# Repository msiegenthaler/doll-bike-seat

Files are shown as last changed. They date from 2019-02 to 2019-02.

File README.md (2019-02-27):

# Doll Bike Seat

OpenSCAD model for a bike seat for dolls for 3D printing.

The seat fits a Kokua Like-to-Bike children bike.

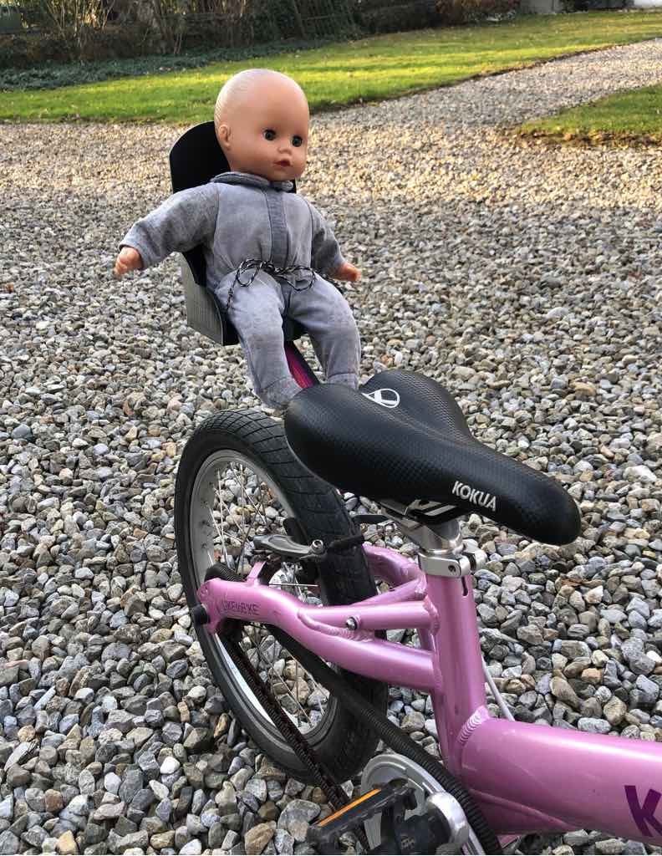
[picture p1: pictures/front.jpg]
Front

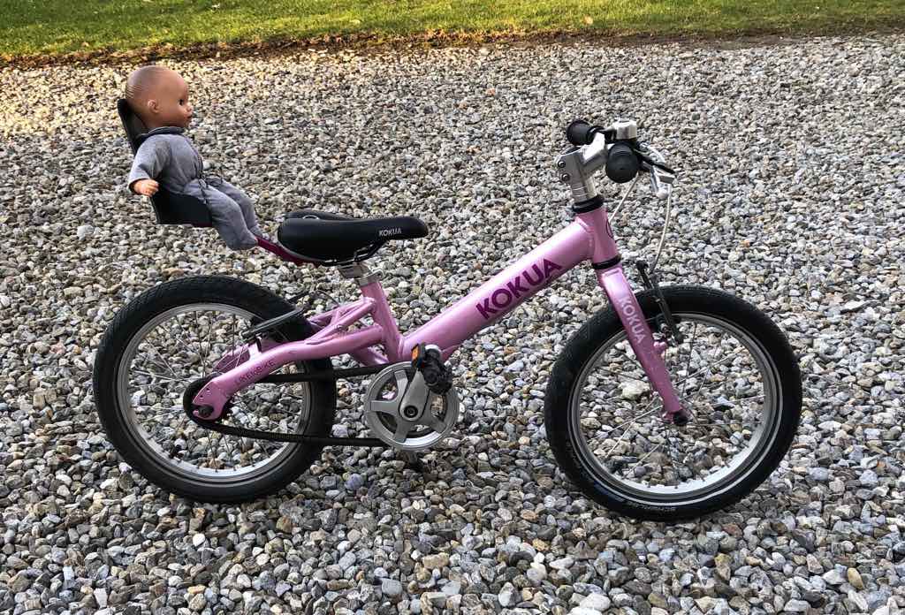
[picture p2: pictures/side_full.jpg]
Full

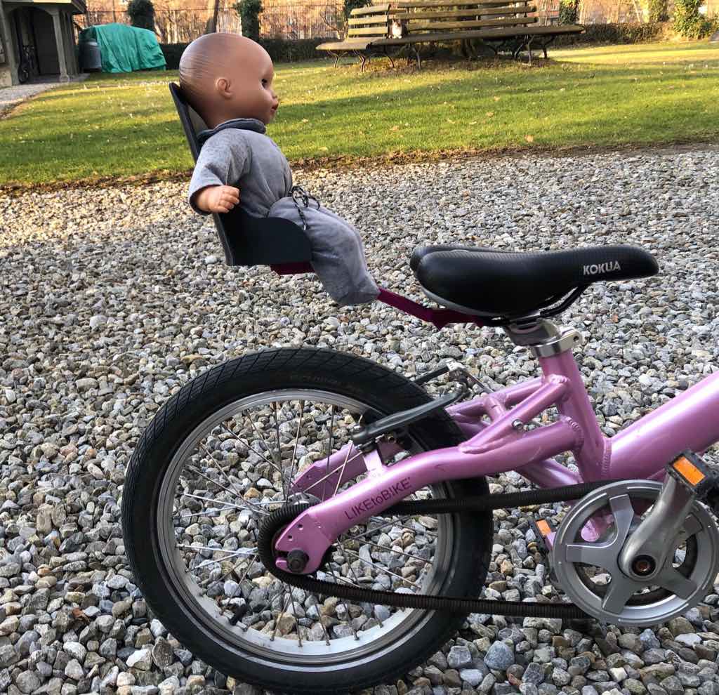
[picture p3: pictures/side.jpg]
Side

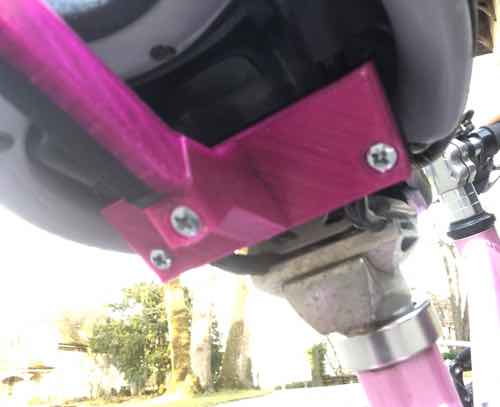
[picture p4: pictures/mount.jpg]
Holder


## Printing

All parts were printed using PET. PLA/ABS are not strong enough.

Here's the recommended settings per part:

- seat: 20% infill, no support
- seat holder: 50% infill, no support
- case top: 50% infill, no support
- case bottom: 50% infill, no support
- rod: 60% infill, support on build plate

## Assembling

You need 6 flat-heat M4 screws and 6 M4 nuts to assemble the parts.

The screws should have the following lengths:

- 3x 10mm M4 (for the seat)
- 2x 15mm M4 (for the case left/right)
- 1x 50mm M4 (for the case middle)

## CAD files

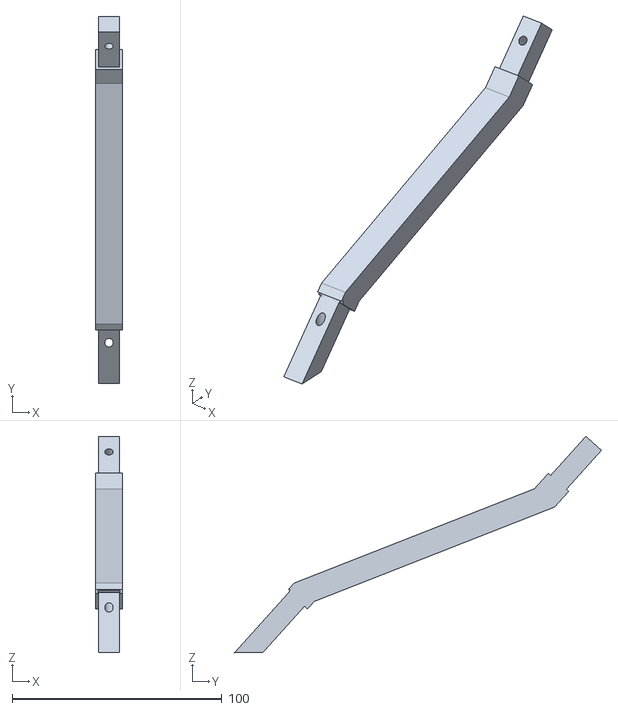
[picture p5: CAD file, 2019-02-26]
models/rod_v9.stl
13.0 x 174.8 x 103.1

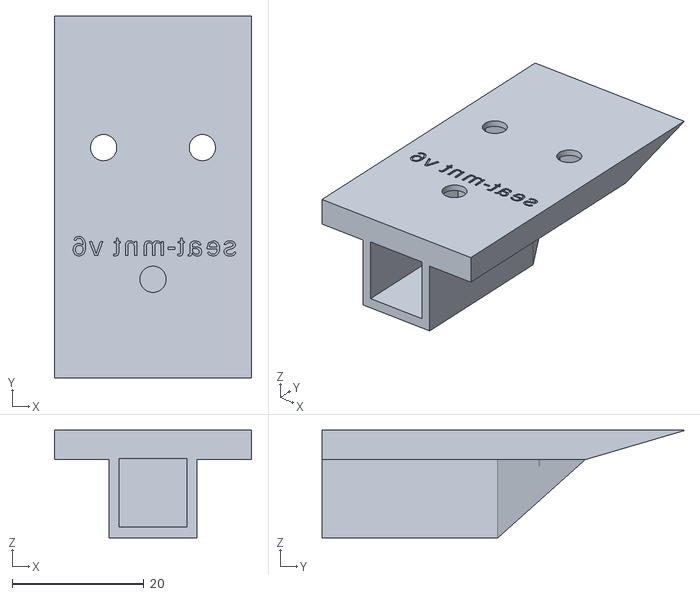
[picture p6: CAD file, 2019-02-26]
models/seat_holder-v6.stl
30.0 x 55.0 x 16.4

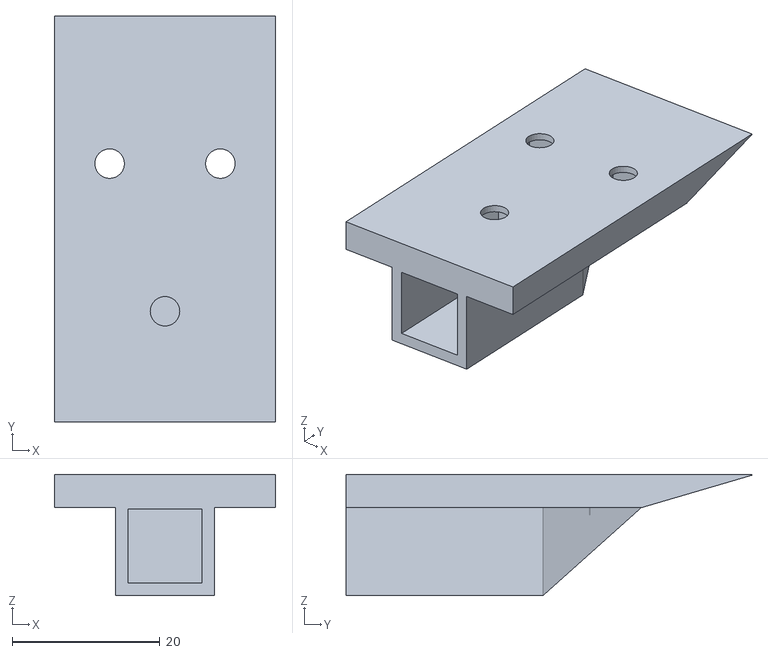
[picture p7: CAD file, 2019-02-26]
models/seat_holder-v5.stl
30.0 x 55.0 x 16.4

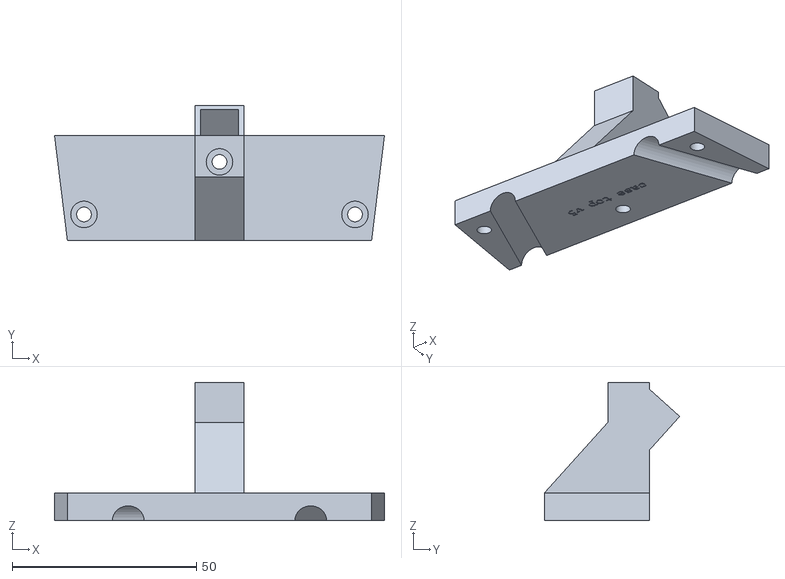
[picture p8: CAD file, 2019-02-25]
models/hold_top-v5.stl
89.5 x 36.7 x 37.5

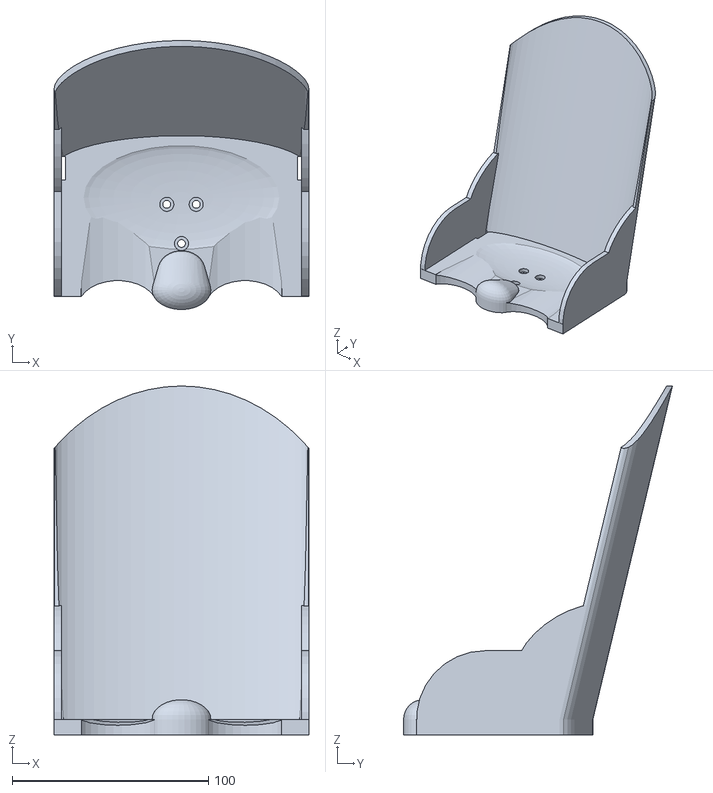
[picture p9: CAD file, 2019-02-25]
models/seat-v4.stl
130.0 x 137.1 x 178.0

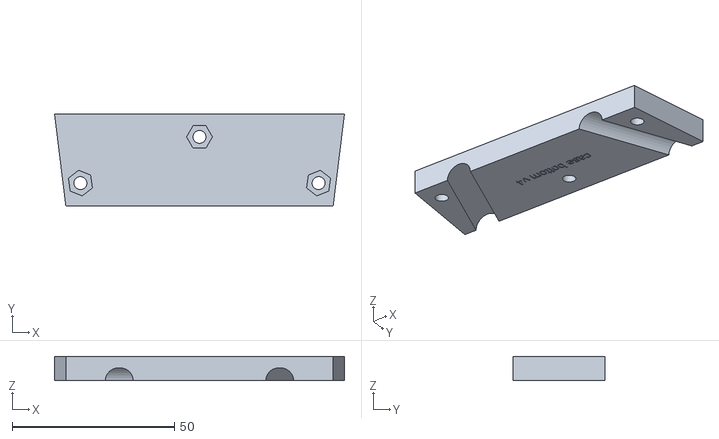
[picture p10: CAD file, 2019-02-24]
models/hold_bottom-v4.stl
89.5 x 28.5 x 7.50

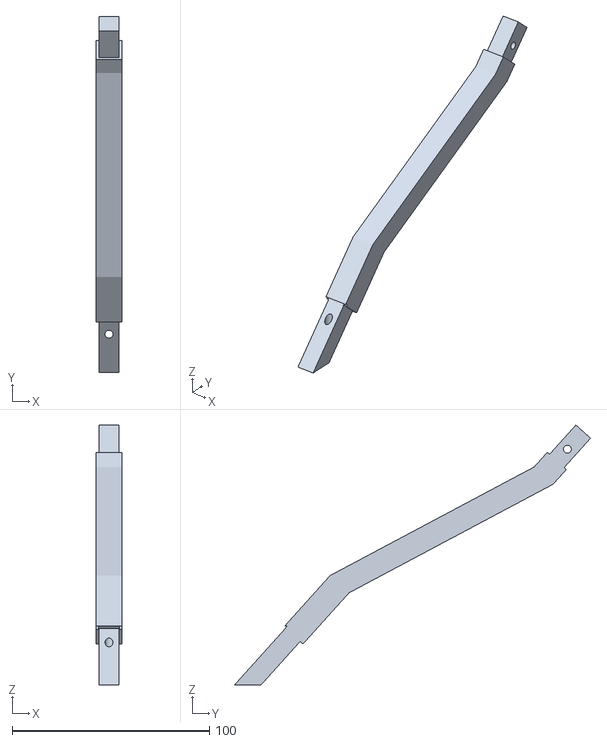
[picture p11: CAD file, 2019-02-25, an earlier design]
models/rod_v7.stl
13.0 x 180.4 x 131.7

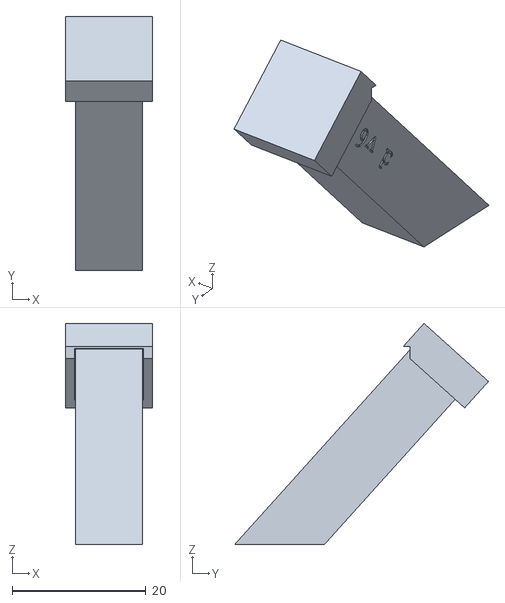
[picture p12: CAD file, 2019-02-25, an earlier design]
models/rod_v6.stl
13.0 x 38.0 x 33.1

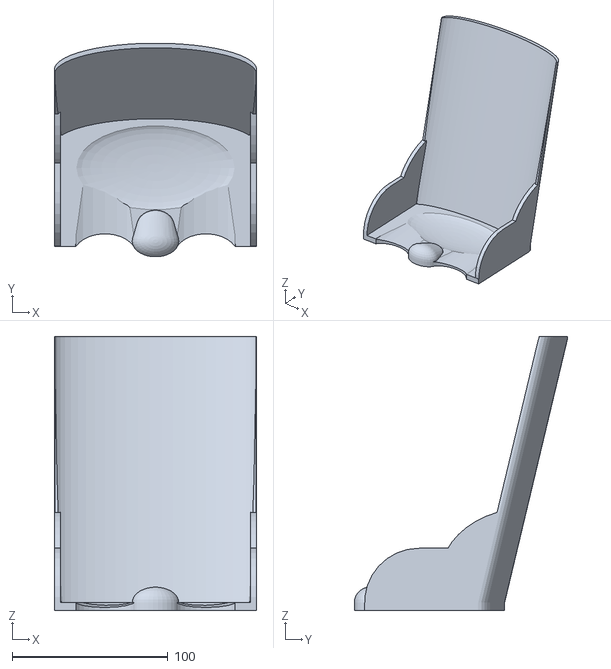
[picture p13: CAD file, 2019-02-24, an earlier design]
models/seat-v3.stl
130.0 x 137.1 x 176.0

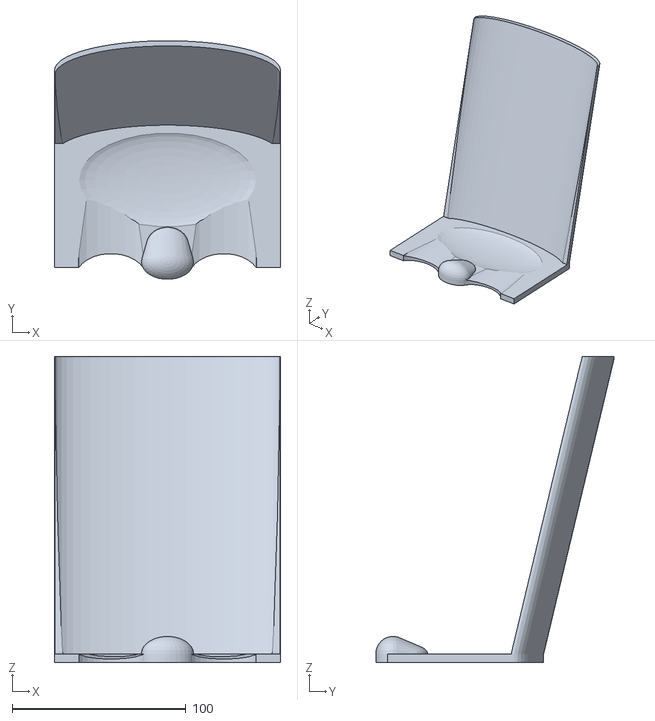
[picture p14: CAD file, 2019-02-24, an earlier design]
models/seat-v2.stl
130.0 x 137.1 x 176.0

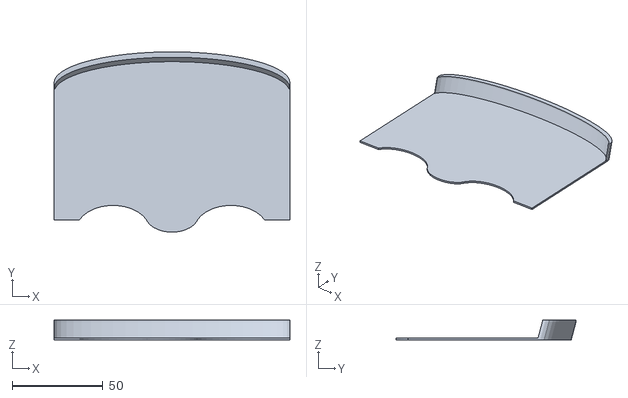
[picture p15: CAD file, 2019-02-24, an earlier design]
models/seat-v1.stl
130.0 x 99.3 x 11.0

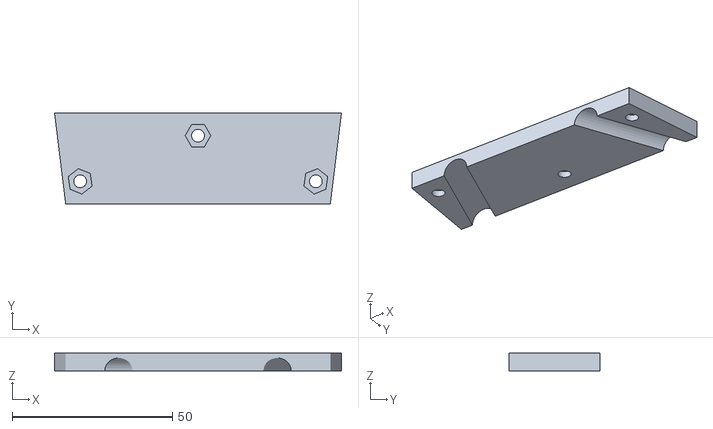
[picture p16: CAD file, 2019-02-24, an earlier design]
models/hold_bottom-v3.stl
89.5 x 28.5 x 5.50

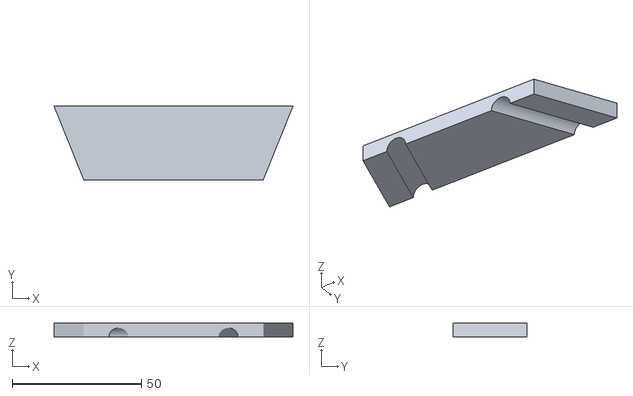
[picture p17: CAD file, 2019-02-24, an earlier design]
models/hold_bottom-v1.stl
92.5 x 28.5 x 5.50

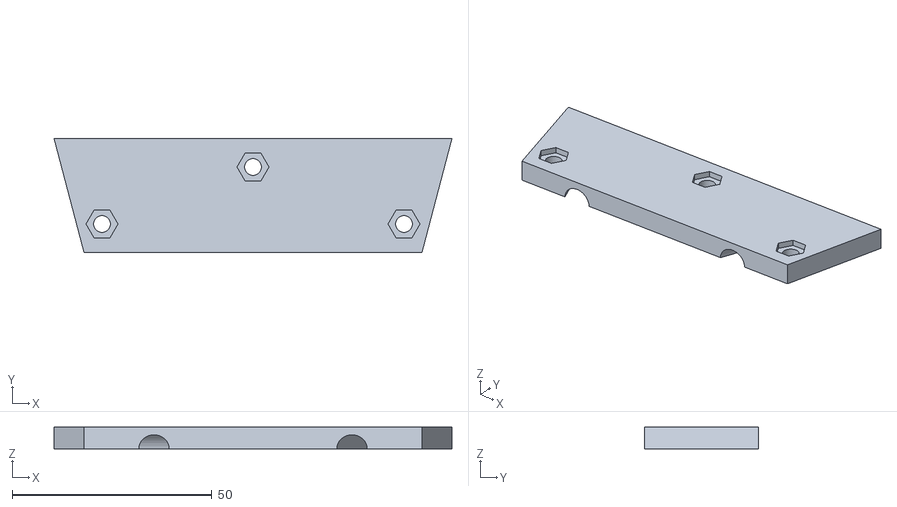
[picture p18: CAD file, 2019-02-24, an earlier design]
models/hold_bottom-v2.stl
99.5 x 28.5 x 5.50

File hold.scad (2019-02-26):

version = "9";
include <engraving.scad>
include <screw.scad>

top_gap = 65.5;
bottom_gap = 42.5;
height = 28.5;
pipe_r = 3.5;
pipe_r_gap = 0.5;


side_protrusion_top = 5;
side_protrusion_bottom = 13;
screw_offset_x = bottom_gap/2 + 15.5;
min_thickness = 4;

include <rod.scad>

// case_bottom();
// case_top();
rod();

module case_top() {
  difference() {
    union() {
      basic_case();
      rod_holder();
    }
    pipe_slots();
    top_screws_negative();
    rod_in_case(enlarge=rod_gap);
    translate([0,0,-50]) cube([100,100,100], center=true);
    engraving("case top");
  }
}

module rod_holder() {
  d = min_thickness+pipe_r;
  w = rod_in_w + (rod_holder_wall+rod_gap)*2;
  h = rod_in_h + (rod_holder_wall+rod_gap)*2;
  translate([-w/2,-height/2,0]) translate([0,0,d]) rotate([-rod_angle,0,0])
    cube([w,h,rod_holder_len]);

  h2 = height/2-3;
  l2 = 37.5;
  translate([-w/2,height/2-h2,0])
    cube([w,h2,l2]);
}

module rod() {
  y_offset = -height/2+rod_outset*0.33;
  difference() {
    union() {
      rod_in_case();
      rod_1(y_offset);
    }
    top_screws_negative();
    case_top();
    translate([-rod_in_w/2,10,25]) rotate([-rod_angle,0,0]) rotate([0,90,0])
      engraving("rod");
  }
}

module rod_1(y_offset) {
  d = min_thickness+pipe_r;
  w = rod_in_w + 2*rod_outset;
  h = rod_in_h + 2*rod_outset;
  weird_l_delta = 0.4;
  translate([w/2,y_offset,d]) rotate([-rod_angle,0,0]) rotate([0,-90, 0]) {
    translate([rod_holder_len-weird_l_delta,0,0]) linear_extrude(w) translate([0,-rod_delta_h]) {
      polygon(points=[[0,rod_delta_h],    [rod_low_l,rod_delta_h],
        [rod_low_l+rod_up_l,0],            [rod_low_l+rod_up_l+rod_high_l,0],
        [rod_low_l+rod_up_l+rod_high_l,h], [rod_low_l+rod_up_l,h],
        [rod_low_l,rod_delta_h+h],         [0, rod_delta_h+h]]);
    }
  }

  // top bolt
  z = rod_holder_len-weird_l_delta+rod_low_l+rod_up_l+rod_high_l;
  translate([0,y_offset,d]) rotate([-rod_angle,0,0]) {
    translate([-rod_in_w/2,-rod_delta_h+rod_outset,z])
      difference() {
        cube([rod_in_w,rod_in_h,rod_top_inside]);
        translate([rod_in_w/2,rod_in_h,rod_top_screw_in]) rotate([90,0,0])
          screw_negative(rod_in_h);
      }
  }
}

module rod_in_case(enlarge=0, rod_distance=0) {
  l = 40;
  d = min_thickness+pipe_r;
  w = rod_in_w + enlarge*2;
  h = rod_in_h + enlarge*2;
  difference() {
    translate([-w/2,-height/2+rod_holder_wall*1.3-enlarge*1.3,0]) translate([0,0,d]) rotate([-rod_angle,0,0])
      cube([w,h,l]);
    cube([top_gap, height, (d+rod_distance)*2], center=true);
  }
}

module top_screws_negative() {
  translate([0, height/4, 0])
    screw_negative(min_thickness+pipe_r+30, top=true, extend_top = 5);
  translate([screw_offset_x, -height/4, 0])
    screw_negative(min_thickness+pipe_r, top=true);
  translate([-screw_offset_x, -height/4, 0])
    screw_negative(min_thickness+pipe_r, top=true);
}

module case_bottom() {
  screw_l = min_thickness+pipe_r;
  difference() {
    basic_case();
    pipe_slots();
    translate([0, height/4, screw_l]) mirror([0,0,1])
      screw_negative(screw_l, bottom=true);
    translate([screw_offset_x, -height/4, screw_l]) rotate([0,0,82]) mirror([0,0,1])
      screw_negative(screw_l, bottom=true);
    translate([-screw_offset_x, -height/4, screw_l]) rotate([0,0,-82]) mirror([0,0,1])
      screw_negative(screw_l, bottom=true);
    engraving("case bottom");
  }
}

module basic_case() {
  xt = top_gap/2 + pipe_r*2+ side_protrusion_top;
  xb = bottom_gap/2 + pipe_r*2 + side_protrusion_bottom;
  h = height/2;
  linear_extrude(min_thickness + pipe_r) 
    polygon(points=[[-xt,h], [xt,h], [xb,-h], [-xb,-h]]);
}

module pipe_slots() {
  d = (top_gap + bottom_gap) / 4;
  translate([-d-pipe_r,0,0]) pipe_slot();
  translate([d+pipe_r,0,0]) mirror([1,0,0]) pipe_slot();
}

module pipe_slot() {
  r = pipe_r + pipe_r_gap; 
  a = atan((top_gap-bottom_gap)/2 / height);
  h = height+(r*8);
  rotate([0,0,a])
    translate([0,h/2,0]) rotate([90,0,0])
      cylinder(r=r, h=h, $fs=0.3);
}

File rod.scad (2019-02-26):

rod_in_w = 10;
rod_in_h = 10;
rod_holder_wall = 1.5;
rod_outset = rod_holder_wall;
rod_holder_len = 40;
rod_gap = 0.2;
rod_angle = 90-48;
rod_delta_h = -55;
rod_low_l = 5;
rod_up_l = 110;
rod_high_l = 10;
rod_top_inside = 25;
rod_top_screw_in = 15;

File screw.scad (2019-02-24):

module screw_negative(h, top=false, bottom=false, extend_top=0, extend_bottom=0) {
  screw_d = 4;  screw_d_plus = 0;
  head_d = 7;   head_d_plus = 0.2;  head_dimple= 3;
  nut_d = 8;    nut_d_plus = 0;     nut_dimple = 3.5;
  cylinder(d=screw_d+screw_d_plus, h=h, $fs=0.3);
  if (top) {
    translate([0, 0, h-head_dimple])
      cylinder(d=head_d+head_d_plus, h=head_dimple+extend_top, $fs=0.3);
  }
  if (bottom) {
    translate([0,0,-extend_bottom])
      cylinder(d=nut_d+nut_d_plus, h=nut_dimple+extend_bottom, $fn=6);
  }
}

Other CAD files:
seat.scad
engraving.scad

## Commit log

2019-02-24 fix: screw diameter, width and nuts
    [hold-v3.stl, hold.scad]
2019-02-24 feat: add top of case
    [hold.scad]
2019-02-24 fix: too flexible
    [hold.scad]
2019-02-24 feat: add engravings
    [hold-v4.stl, hold.scad]
2019-02-24 feat: add base version of the seat
    [seat-v1.stl, seat.scad]
2019-02-24 refactor: engraving
    [engraving.scad, hold.scad, seat.scad]
2019-02-24 feat: stabler back and more ergonomic seat base
    [seat-v2.stl, seat.scad]
2019-02-24 feat: add side protection
    [seat-v3.stl, seat.scad]
2019-02-24 refactor: factor out screw
    [hold.scad, screw.scad]
2019-02-24 fix: screws with both bottom and top
    [hold.scad, screw.scad]
2019-02-24 feat: add holder and screws
    [seat.scad]
2019-02-24 feat: nicer top of the back
    [seat.scad]
2019-02-25 feat: add holes for belt
    [seat-v4.stl, seat.scad]
2019-02-25 feat: add rod holder to case
    [hold.scad, hold_bottom-v1.stl, hold_bottom-v2.stl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]
2019-02-25 wip: work on rod
    [hold.scad, rod_v6.stl]
2019-02-25 feat: add complete rod
    [hold.scad, rod_v7.stl]
2019-02-26 refactor: move rod sizing to separate file
    [hold.scad, rod.scad]
2019-02-26 feat: complete seat-holder
    [rod.scad, seat.scad, seat_holder-v5.stl]
2019-02-26 fix: adjust rod after fitting
    [hold.scad, rod.scad]
2019-02-26 feat: change engraving font for better readability
    [engraving.scad]
2019-02-26 fix: engraving for seat-mount
    [engraving.scad, seat.scad]
2019-02-26 fix: too narrow rod hole on seat
    [seat.scad, seat_holder-v6.stl]
2019-02-26 fix: rod top screw hole
    [hold.scad, rod.scad, rod_v9.stl]
2019-02-26 doc: add assembly and printing instructions
